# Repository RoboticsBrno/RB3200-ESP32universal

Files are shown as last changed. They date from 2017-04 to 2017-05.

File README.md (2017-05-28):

# RB3200 - ESP32 universal board

The ESP32 board you have always dreamed of by RobotikaBrno.cz!

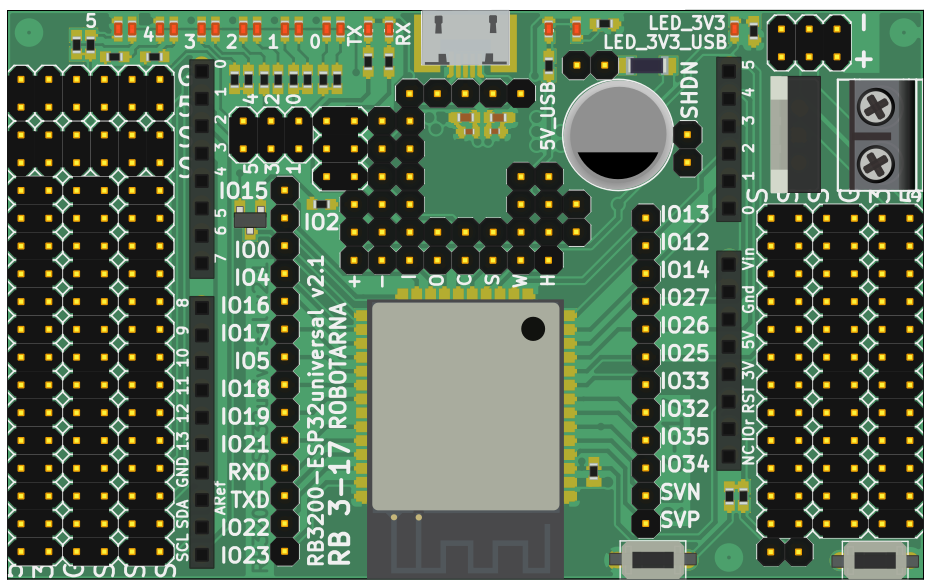
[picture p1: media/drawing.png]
Board drawing


## Features

- 4 pin headers for each of the ESP32-WROOM-32 pins
    - pin headers closest to the ESP32 module are directly exposed from the
      module
    - pin headers further from the module are protected by a serial 180R
      resistor - so you can attach e.g. a LED directly or you don't have to
      worry if you accidentally switch you grounded input to output.
    - each pin has its own 5V, 3V3 and GND pin
- Arduino Uno compatible headerincluded
- USB2Serial chip for easy button-less programming
- support for an external power supply with high-current voltage regulator
- diagnostic LEDs

## Populated board

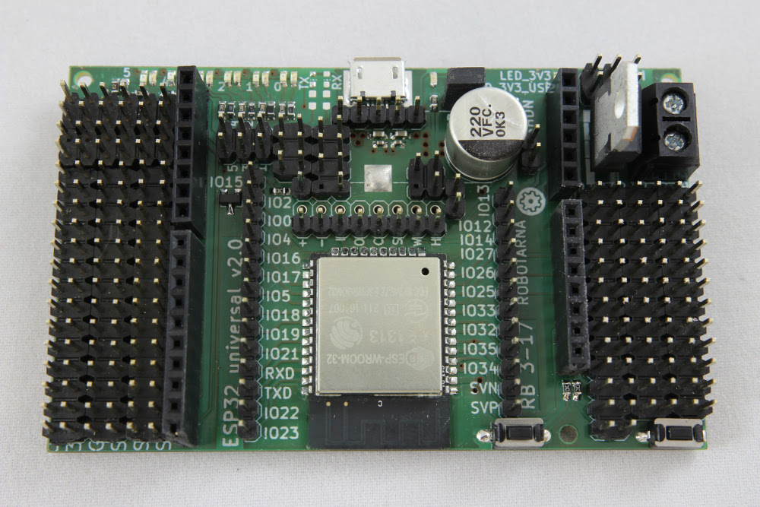
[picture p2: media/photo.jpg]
Board pohoto


## Manufacturing

There are pre-exported gerber files in the `gerbers` directory. This directory
is always up-to-date for every release (the master branch). There is also the
`bom.tsv` file which contains BOM with order codes for Farnell, TS, Mouser and
DigiKey. Note that the current development branch (`vX.Y`) does not guarantee
up-to-date gerber and BOM files.

As our board features many pin headers and you might not want to populate them
all, we did **not** include them in the BOM. Keep that please in mind when
ordering the components.

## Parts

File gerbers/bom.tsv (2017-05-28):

Qty | Value | Device | Package | Parts | Description | DIGIKEY | FARNELL | MANUFACTURER | MOUSER | MPN | RS
1 |  | PINHD-1X12 | 1X12 | JP1 | PIN HEADER
1 |  | PINHD-1X14 | 1X14 | JP5 | PIN HEADER
4 |  | PINHD-1X2 | 1X02 | EN, JP36, JP38, VUSB | PIN HEADER
1 |  | PINHD-1X5 | 1X05 | USB | PIN HEADER
1 |  | PINHD-1X8 | 1X08 | JP11 | PIN HEADER
3 |  | PINHD-2X12 | 2X12 | JP2, JP3, PWR_1 | PIN HEADER
3 |  | PINHD-2X14 | 2X14 | JP6, JP7, PWR_2 | PIN HEADER
3 |  | PINHD-2X3 | 2X03 | LEDS, VCC, VCCIO | PIN HEADER
2 |  | PINHD-2X6 | 2X06 | +5V, SERVOS | PIN HEADER
1 | 100k | R-EU_R0603 | R0603 | R37 | RESISTOR, European symbol | 311-100KHRCT-ND | 9238727 |  | 603-RC0603FR-07100KL |  | 566-787
6 | 100n/16V | C-EUC0402 | C0402 | C1, C6, C7, C11, C20, C21 | CAPACITOR, European symbol | 732-7478-1-ND | 2533923 |  | 710-885012105001 |  | 788-2871
6 | 10k | R-EU_R0603 | R0603 | R4, R5, R35, R50, R51, R52 | RESISTOR, European symbol | 311-10KGRCT-ND | 9238603 |  | 603-RC0603FR-0710KL |  | 213-2418
28 | 180R | R-EU_R0603 | R0603 | R6, R7, R8, R9, R10, R11, R12, R13, R14, R15, R16, R17, R18, R19, R20, R21, R22, R23, R24, R25, R27, R28, R29, R30, R31, R32, R33, R34 | RESISTOR, European symbol | 311-180HRCT-ND | 9238395 |  | 603-RC0603FR-07180RL |  | 566-412
1 | 1n/50V | C-EUC0603 | C0603 | C12 | CAPACITOR, European symbol | 399-1082-1-ND | 1414608 |  | 80-C0603C102K5R |  | 264-4551
1 | 330u/16V | CPOL-EUE5-10.5 | E5-10,5 | C37 | POLARIZED CAPACITOR, European symbol | 493-6629-1-ND | 9692045 |  | 140-REA331M1CBK0811P |  | 707-5840
11 | 470R | R-EU_R0603 | R0603 | R1, R2, R3, R26, R36, R38, R40, R42, R44, R46, R48 | RESISTOR, European symbol | 311-470HRCT-ND | 9238441 |  | 603-RC0603FR-07470RL |  | 566-547
4 | 4u7/16V | C-EUC0603 | C0603 | C2, C3, C4, C5 | CAPACITOR, European symbol | 478-1253-1-ND | 9227784 |  | 06034D475KAT2A |  | 698-3248
5 | 4u7/16V | C-EUC0805 | C0805 | C8, C9, C10, C67, C70 | CAPACITOR, European symbol | 1276-2970-1-ND | 2320854 |  | 963-EMK212B7475KG-T |  | 766-1037
6 | 680R | R-EU_R0603 | R0603 | R39, R41, R43, R45, R47, R49 | RESISTOR, European symbol | 311-680HRCT-ND | 9238468 |  | 603-RC0603FR-13680RL
1 | 7805 | 78XXS | 78XXS | IC2 | VOLTAGE REGULATOR | 1016-1538-5-ND | 9756078 |  | 701-SP7805V-L |  | 769-5466
1 | ARDUINOR3-BPLACE | ARDUINOR3-BPLACE | ARDUINOR3-BPLACE | U3 | This is a new object for the new Arduino R3 - with extra pins that you may want to use (such as IOref, and duplicated A4/A5
2 | BC337 | NPN-SOT23-BEC | SOT23 | T1, T2 |  | 1727-2919-1-ND | 1081224 |  | 771-BC817-40-T/R |  | 216-9410
1 | CP2102N-28 | CP2102N-28 | QFN28-PAD | IC3 |  | 336-3694-ND | 2577279 | Silicon Labs | 634-CP2102NA01GQFN28 | CP2102 | 526-8841
1 | ESP-WROOM-32 | ESP-WROOM-32 | ESP-WROOM-32 | U1 | Espressif Systems ESP-WROOM-32 | 1738-1294-ND |  | Espressif Systems |  | ESP32-WROMM-32
1 | MKDSN1,5/2-5,08 | MKDSN1,5/2-5,08 | MKDSN1,5/2-5,08 | PWR | MKDSN 1,5/ 2-5,08 Printklemme | 277-5953-ND | 2490945 |  | 651-1890963 |  | 804-5118
21 | PINH1X01 | PINH1X01 | 1X01 | !CTS, !DCD, !DSR, !DTR, !RESET, !RTS, !SUSPEND, CHR0, CHR1, CHREN, IO0/TXLED, IO1/RXLED, IO2/RS485, IO3/WAKEUP, IO4, IO5, IO6, RI/CLK, RXD, SUSPEND, TXD
2 | TACTM-35N-F | TACTM-35N-F | TACTM-35N-F | B1, B2 |  | CKN1574TR-ND | 2079520 |  | 611-PTS635SL43SMTRLF |  | 135-9609
1 | UM18533 | UM185XX | SOT23-5 | U2 |  | 296-17580-1-ND | 1135395 | Texas Instruments | 595-TPS73033DBVR | TPS73033DBVT | 620-1401
1 | USB-MICRO-B-BOTTOM | USB-MICRO-B-BOTTOM | USB-MICRO-B-BOTTOM-MOLEX | X1 |  | WM17141CT-ND | 1568026 |  | 538-47346-0001 |  | 702-5475
8 | green | LEDCHIPLED_0603 | CHIPLED_0603 | LED0P, LED1P, LED2P, LED3P, LED4P, LED5P, LED_3V3, LED_3V3_USB | LED | 160-1446-1-ND | 2293494 |  | 859-LTST-C191KGKT |  | 872-1799
6 | red | LEDCHIPLED_0603 | CHIPLED_0603 | LED0N, LED1N, LED2N, LED3N, LED4N, LED5N | LED | 160-1447-1-ND | 2322071 |  | 859-LTST-C191KRKT |  | 127-8415
3 | skl34 | SHOTTKY-SOD123 | SOD123 | D1, D2, D5
3 | yellow | LEDCHIP-LED0603 | CHIP-LED0603 | LED1, LED2, LED3 | LED | 732-4981-1-ND | 2322074 |  | 710-150060YS75000 |  | 815-4219

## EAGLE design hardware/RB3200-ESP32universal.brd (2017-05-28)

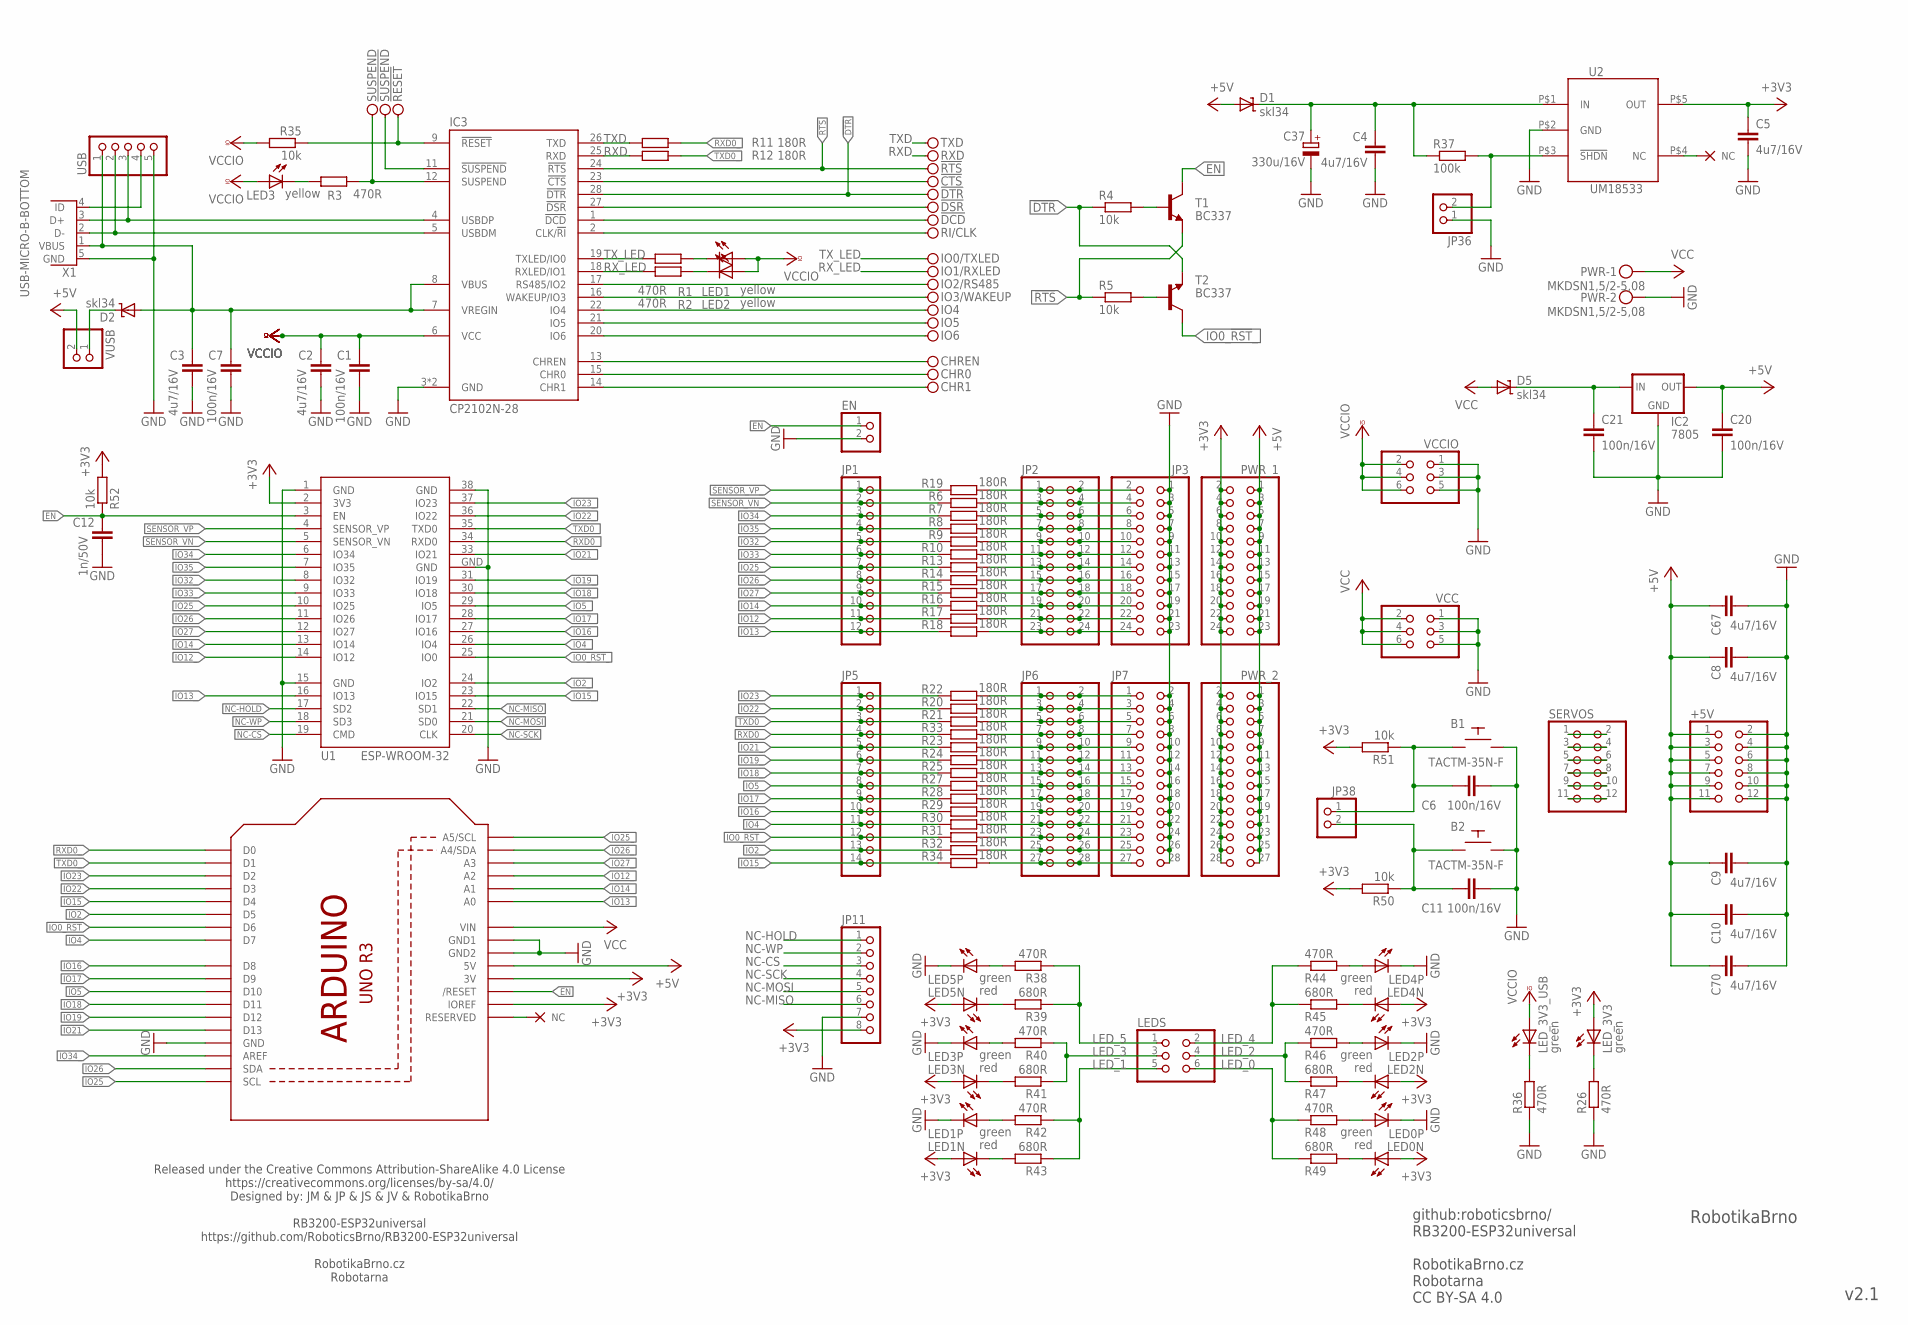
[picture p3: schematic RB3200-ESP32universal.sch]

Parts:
!CTS: PINH1X01; 1X01; DIGIKEY WM14724-ND
!DCD: PINH1X01; 1X01; DIGIKEY WM14724-ND
!DSR: PINH1X01; 1X01; DIGIKEY WM14724-ND
!DTR: PINH1X01; 1X01; DIGIKEY WM14724-ND
!RESET: PINH1X01; 1X01; DIGIKEY WM14724-ND
!RTS: PINH1X01; 1X01; DIGIKEY WM14724-ND
!SUSPEND: PINH1X01; 1X01; DIGIKEY WM14724-ND
+5V: PINHD-2X6; 2X06; DIGIKEY A122662-ND
B1, B2: TACTM-35N-F; DIGIKEY CKN1574TR-ND
C1, C6, C7, C11, C20, C21: 100n/16V; C0402; DIGIKEY 732-7478-1-ND
C2, C3, C4, C5: 4u7/16V; C0603; DIGIKEY 478-1253-1-ND
C8, C9, C10, C67, C70: 4u7/16V; C0805; DIGIKEY 1276-2970-1-ND
C12: 1n/50V; C0603; DIGIKEY 399-1082-1-ND
C37: 330u/16V; E5-10,5; DIGIKEY 493-6629-1-ND
CHR0, CHR1: PINH1X01; 1X01; DIGIKEY WM14724-ND
CHREN: PINH1X01; 1X01; DIGIKEY WM14724-ND
D1, D2, D5: skl34; SOD123
EN: PINHD-1X2; 1X02; DIGIKEY 3M9457-02-ND
IC2: 7805; 78XXS; DIGIKEY 1016-1538-5-ND
IC3: CP2102N-28; QFN28-PAD; MPN CP2102; DIGIKEY 336-3694-ND
IO0/TXLED, IO1/RXLED, IO2/RS485, IO3/WAKEUP, IO4, IO5, IO6: PINH1X01; 1X01; DIGIKEY WM14724-ND
JP1: PINHD-1X12; 1X12; DIGIKEY WM50014-12-ND
JP2, JP3: PINHD-2X12; 2X12; DIGIKEY WM8148-ND
JP5: PINHD-1X14; 1X14; FARNELL 2356164
JP6, JP7: PINHD-2X14; 2X14; DIGIKEY WM8150-ND
JP11: PINHD-1X8; 1X08; DIGIKEY A122911-ND
JP36, JP38: PINHD-1X2; 1X02; DIGIKEY 3M9457-02-ND
LED0N, LED1N, LED2N, LED3N, LED4N, LED5N: red; CHIPLED_0603; DIGIKEY 160-1447-1-ND
LED0P, LED1P, LED2P, LED3P, LED4P, LED5P: green; CHIPLED_0603; DIGIKEY 160-1446-1-ND
LED1, LED2, LED3: yellow; CHIP-LED0603; DIGIKEY 732-4981-1-ND
LEDS: PINHD-2X3; 2X03; DIGIKEY A122915-ND
LED_3V3, LED_3V3_USB: green; CHIPLED_0603; DIGIKEY 160-1446-1-ND
PWR: MKDSN1,5/2-5,08; DIGIKEY 277-5953-ND
PWR_1: PINHD-2X12; 2X12; DIGIKEY WM8148-ND
PWR_2: PINHD-2X14; 2X14; DIGIKEY WM8150-ND
R1, R2, R3, R26, R36, R38, R40, R42, R44, R46, R48: 470R; R0603; DIGIKEY 311-470HRCT-ND
R4, R5, R35, R50, R51, R52: 10k; R0603; DIGIKEY 311-10KGRCT-ND
R6, R7, R8, R9, R10, R11, R12, R13, R14, R15, R16, R17, R18, R19, R20, R21, R22, R23, R24, R25, R27, R28, R29, R30, R31, R32, R33, R34: 180R; R0603; DIGIKEY 311-180HRCT-ND
R37: 100k; R0603; DIGIKEY 311-100KHRCT-ND
R39, R41, R43, R45, R47, R49: 680R; R0603; DIGIKEY 311-680HRCT-ND
RI/CLK: PINH1X01; 1X01; DIGIKEY WM14724-ND
RXD: PINH1X01; 1X01; DIGIKEY WM14724-ND
SERVOS: PINHD-2X6; 2X06; DIGIKEY A122662-ND
SUSPEND: PINH1X01; 1X01; DIGIKEY WM14724-ND
T1, T2: BC337; SOT23; DIGIKEY 1727-2919-1-ND
TXD: PINH1X01; 1X01; DIGIKEY WM14724-ND
U1: ESP-WROOM-32; MPN ESP32-WROMM-32; DIGIKEY 1738-1294-ND
U2: UM18533; SOT23-5; MPN TPS73033DBVT; DIGIKEY 296-17580-1-ND
U3: ARDUINOR3-BPLACE
USB: PINHD-1X5; 1X05; DIGIKEY 732-5318-ND
VCC: PINHD-2X3; 2X03; DIGIKEY A122915-ND
VCCIO: PINHD-2X3; 2X03; DIGIKEY A122915-ND
VUSB: PINHD-1X2; 1X02; DIGIKEY 3M9457-02-ND
X1: USB-MICRO-B-BOTTOM; USB-MICRO-B-BOTTOM-MOLEX; DIGIKEY WM17141CT-ND

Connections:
3V3_IN: C4.1, C37.+, D1.C, R37.1, U2.P$1 (IN)
5V_USB: D2.C, VUSB.1
!DTR: !DTR.1, IC3.28 (!DTR), R4.1, T2.2 (E)
!DTR_B: R4.2, T1.1 (B)
!RESET: !RESET.1, IC3.9 (!RESET), R35.1
!RTS: !RTS.1, IC3.24 (!RTS), R5.1, T1.2 (E)
!RTS_B: R5.2, T2.1 (B)
!SHDN: JP36.2, R37.2, U2.P$3 (!SHDN)
!SUSPEND: !SUSPEND.1, IC3.11 (!SUSPEND)
+3V3: C5.1, JP11.8, LED0N.A, LED1N.A, LED2N.A, LED3N.A, LED4N.A, LED5N.A, LED_3V3.A, PWR_1.2, PWR_1.4, PWR_1.6, PWR_1.8, PWR_1.10, PWR_1.12, PWR_1.14, PWR_1.16, PWR_1.18, PWR_1.20, PWR_1.22, PWR_1.24, PWR_2.2, PWR_2.4, PWR_2.6, PWR_2.8, PWR_2.10, PWR_2.12, PWR_2.14, PWR_2.16, PWR_2.18, PWR_2.20, PWR_2.22, PWR_2.24, PWR_2.26, PWR_2.28, R50.2, R51.2, R52.2, U1.2 (3V3), U2.P$5 (OUT), U3.3V, U3.IOREF
+5V: +5V.1, +5V.3, +5V.5, +5V.7, +5V.9, +5V.11, C8.1, C9.1, C10.1, C20.1, C67.1, C70.1, D1.A, IC2.OUT, PWR_1.1, PWR_1.3, PWR_1.5, PWR_1.7, PWR_1.9, PWR_1.11, PWR_1.13, PWR_1.15, PWR_1.17, PWR_1.19, PWR_1.21, PWR_1.23, PWR_2.1, PWR_2.3, PWR_2.5, PWR_2.7, PWR_2.9, PWR_2.11, PWR_2.13, PWR_2.15, PWR_2.17, PWR_2.19, PWR_2.21, PWR_2.23, PWR_2.25, PWR_2.27, U3.5V, VUSB.2
BTN0: B1.P$4, C6.2, JP38.1, R51.1
BTN1: B2.P$4, C11.2, JP38.2, R50.1
CHR0: CHR0.1, IC3.15 (CHR0)
CHR1: CHR1.1, IC3.14 (CHR1)
CHREN: CHREN.1, IC3.13 (CHREN)
CLK/!RI: IC3.2 (CLK/!RI), RI/CLK.1
DCD: !DCD.1, IC3.1 (!DCD)
DM: IC3.5 (USBDM), USB.2, X1.2 (D-)
DP: IC3.4 (USBDP), USB.3, X1.3 (D+)
DSR: !DSR.1, IC3.27 (!DSR)
EN: C12.1, EN.1, R52.1, T1.3 (C), U1.3 (EN), U3.RESET (/RESET)
GND: +5V.2, +5V.4, +5V.6, +5V.8, +5V.10, +5V.12, B1.P$2, B2.P$2, C1.2, C2.2, C3.2, C4.2, C5.2, C6.1, C7.2, C8.2, C9.2, C10.2, C11.1, C12.2, C20.2, C21.2, C37.-, C67.2, C70.2, EN.2, IC2.GND, IC3.3 (GND), IC3.PAD (GND), JP3.1, JP3.3, JP3.5, JP3.7, JP3.9, JP3.11, JP3.13, JP3.15, JP3.17, JP3.19, JP3.21, JP3.23, JP7.2, JP7.4, JP7.6, JP7.8, JP7.10, JP7.12, JP7.14, JP7.16, JP7.18, JP7.20, JP7.22, JP7.24, JP7.26, JP7.28, JP11.7, JP36.1, LED0P.C, LED1P.C, LED2P.C, LED3P.C, LED4P.C, LED5P.C, PWR.2, R26.1, R36.1, U1.1 (GND), U1.15 (GND), U1.38 (GND), U1.GND, U2.P$2 (GND), U3.GND, U3.GND1, U3.GND2, USB.5, VCC.1, VCC.3, VCC.5, VCCIO.1, VCCIO.3, VCCIO.5, X1.5 (GND)
IO0_!RST: JP6.23, JP6.24, JP7.23, R31.1, U3.D6
IO0_!RST!_: JP5.12, R31.2, T2.3 (C), U1.25 (IO0)
IO2: JP6.25, JP6.26, JP7.25, R32.1, U3.D5
IO2_: JP5.13, R32.2, U1.24 (IO2)
IO4: JP6.21, JP6.22, JP7.21, R30.1, U3.D7
IO4_: JP5.11, R30.2, U1.26 (IO4)
IO5: JP6.15, JP6.16, JP7.15, R27.1, U3.D10
IO5_: JP5.8, R27.2, U1.29 (IO5)
IO12: JP2.21, JP2.22, JP3.22, R17.1
IO12_: JP1.11, R17.2, U1.14 (IO12), U3.A2
IO13: JP2.23, JP2.24, JP3.24, R18.1
IO13_: JP1.12, R18.2, U1.16 (IO13), U3.A0
IO14: JP2.19, JP2.20, JP3.20, R16.1
IO14_: JP1.10, R16.2, U1.13 (IO14), U3.A1
IO15: JP6.27, JP6.28, JP7.27, R34.1, U3.D4
IO15_: JP5.14, R34.2, U1.23 (IO15)
IO16: JP6.19, JP6.20, JP7.19, R29.1, U3.D8
IO16_: JP5.10, R29.2, U1.27 (IO16)
IO17: JP6.17, JP6.18, JP7.17, R28.1, U3.D9
IO17_: JP5.9, R28.2, U1.28 (IO17)
IO18: JP6.13, JP6.14, JP7.13, R25.1, U3.D11
IO18_: JP5.7, R25.2, U1.30 (IO18)
IO19: JP6.11, JP6.12, JP7.11, R24.1, U3.D12
IO19_: JP5.6, R24.2, U1.31 (IO19)
IO21: JP6.9, JP6.10, JP7.9, R23.1, U3.D13
IO21_: JP5.5, R23.2, U1.33 (IO21)
IO22: JP6.3, JP6.4, JP7.3, R20.1, U3.D3
IO22_: JP5.2, R20.2, U1.36 (IO22)
IO23: JP6.1, JP6.2, JP7.1, R22.1, U3.D2
IO23_: JP5.1, R22.2, U1.37 (IO23)
IO25: JP2.13, JP2.14, JP3.14, R13.1
IO25_: JP1.7, R13.2, U1.10 (IO25), U3.A5 (A5/SCL), U3.SCL
IO26: JP2.15, JP2.16, JP3.16, R14.1
IO26_: JP1.8, R14.2, U1.11 (IO26), U3.A4 (A4/SDA), U3.SDA
IO27: JP2.17, JP2.18, JP3.18, R15.1
IO27_: JP1.9, R15.2, U1.12 (IO27), U3.A3
IO32: JP2.9, JP2.10, JP3.10, R9.1
IO32_: JP1.5, R9.2, U1.8 (IO32)
IO33: JP2.11, JP2.12, JP3.12, R10.1
IO33_: JP1.6, R10.2, U1.9 (IO33)
IO34: JP2.5, JP2.6, JP3.6, R7.1
IO34_: JP1.3, R7.2, U1.6 (IO34), U3.AREF
IO35: JP2.7, JP2.8, JP3.8, R8.1
IO35_: JP1.4, R8.2, U1.7 (IO35)
LED0N: LED0N.C, R49.2
LED0P: LED0P.A, R48.2
LED1N: LED1N.C, R43.2
LED1P: LED1P.A, R42.2
LED2N: LED2N.C, R47.2
LED2P: LED2P.A, R46.2
LED3N: LED3N.C, R41.2
LED3P: LED3P.A, R40.2
LED4N: LED4N.C, R45.2
LED4P: LED4P.A, R44.2
LED5N: LED5N.C, R39.2
LED5P: LED5P.A, R38.2
LED_0: LEDS.6, R48.1, R49.1
LED_1: LEDS.5, R42.1, R43.1
LED_2: LEDS.4, R46.1, R47.1
LED_3: LEDS.3, R40.1, R41.1
LED_3V3: LED_3V3.C, R26.2
LED_3V3_USB: LED_3V3_USB.C, R36.2
LED_4: LEDS.2, R44.1, R45.1
LED_5: LEDS.1, R38.1, R39.1
unnamed: !CTS.1, IC3.23 (!CTS)
unnamed: LED3.C, R3.2
unnamed: SERVOS.1, SERVOS.2
unnamed: SERVOS.3, SERVOS.4
unnamed: SERVOS.5, SERVOS.6
unnamed: SERVOS.7, SERVOS.8
unnamed: SERVOS.9, SERVOS.10
unnamed: SERVOS.11, SERVOS.12
NC-CS: JP11.3, U1.19 (CMD)
NC-HOLD: JP11.1, U1.17 (SD2)
NC-MISO: JP11.6, U1.22 (SD1)
NC-MOSI: JP11.5, U1.21 (SD0)
NC-SCK: JP11.4, U1.20 (CLK)
NC-WP: JP11.2, U1.18 (SD3)
RX-LED: LED2.C, R2.1
RXD: IC3.25 (RXD), R12.1, RXD.1
RXD0: JP6.7, JP6.8, JP7.7, R33.1, U3.D0
RXD0_: JP5.4, R11.2, R33.2, U1.34 (RXD0)
RX_LED: IC3.18 (RXLED/IO1), IO1/RXLED.1, R2.2
SENSOR_VN: JP2.3, JP2.4, JP3.4, R6.1
SENSOR_VN_: JP1.2, R6.2, U1.5 (SENSOR_VN)
SENSOR_VP: JP2.1, JP2.2, JP3.2, R19.1
SENSOR_VP_: JP1.1, R19.2, U1.4 (SENSOR_VP)
SUSPEND: IC3.12 (SUSPEND), R3.1, SUSPEND.1
TX-LED: LED1.C, R1.1
TXD: IC3.26 (TXD), R11.1, TXD.1
TXD0: JP6.5, JP6.6, JP7.5, R21.1, U3.D1
TXD0_: JP5.3, R12.2, R21.2, U1.35 (TXD0)
TX_LED: IC3.19 (TXLED/IO0), IO0/TXLED.1, R1.2
U2_NC: U2.P$4 (NC)
USBID: USB.4, X1.4 (ID)
USBIO3_RS485: IC3.17 (RS485/IO2), IO2/RS485.1
USBIO3_WAKEUP: IC3.16 (WAKEUP/IO3), IO3/WAKEUP.1
USBIO4: IC3.22 (IO4), IO4.1
USBIO5: IC3.21 (IO5), IO5.1
USBIO6: IC3.20 (IO6), IO6.1
VCC: D5.A, PWR.1, VCC.2, VCC.4, VCC.6
VCC->5V: C21.1, D5.C, IC2.IN
VCCIO: C1.1, C2.1, IC3.6 (VCC), LED1.A, LED2.A, LED3.A, LED_3V3_USB.A, R35.2, VCCIO.2, VCCIO.4, VCCIO.6
VUSB: C3.1, C7.1, D2.A, IC3.7 (VREGIN), IC3.8 (VBUS), USB.1, X1.1 (VBUS)

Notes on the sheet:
github:roboticsbrno/ RB3200-ESP32universal RobotikaBrno.cz Robotarna CC BY-SA 4.0
RobotikaBrno
v2.1
Released under the Creative Commons Attribution-ShareAlike 4.0 License https://creativecommons.org/licenses/by-sa/4.0/ Designed by: JM & JP & JS & JV & RobotikaBrno RB3200-ESP32universal https://github.com/RoboticsBrno/RB3200-ESP32universal RobotikaBrno.cz Robotarna

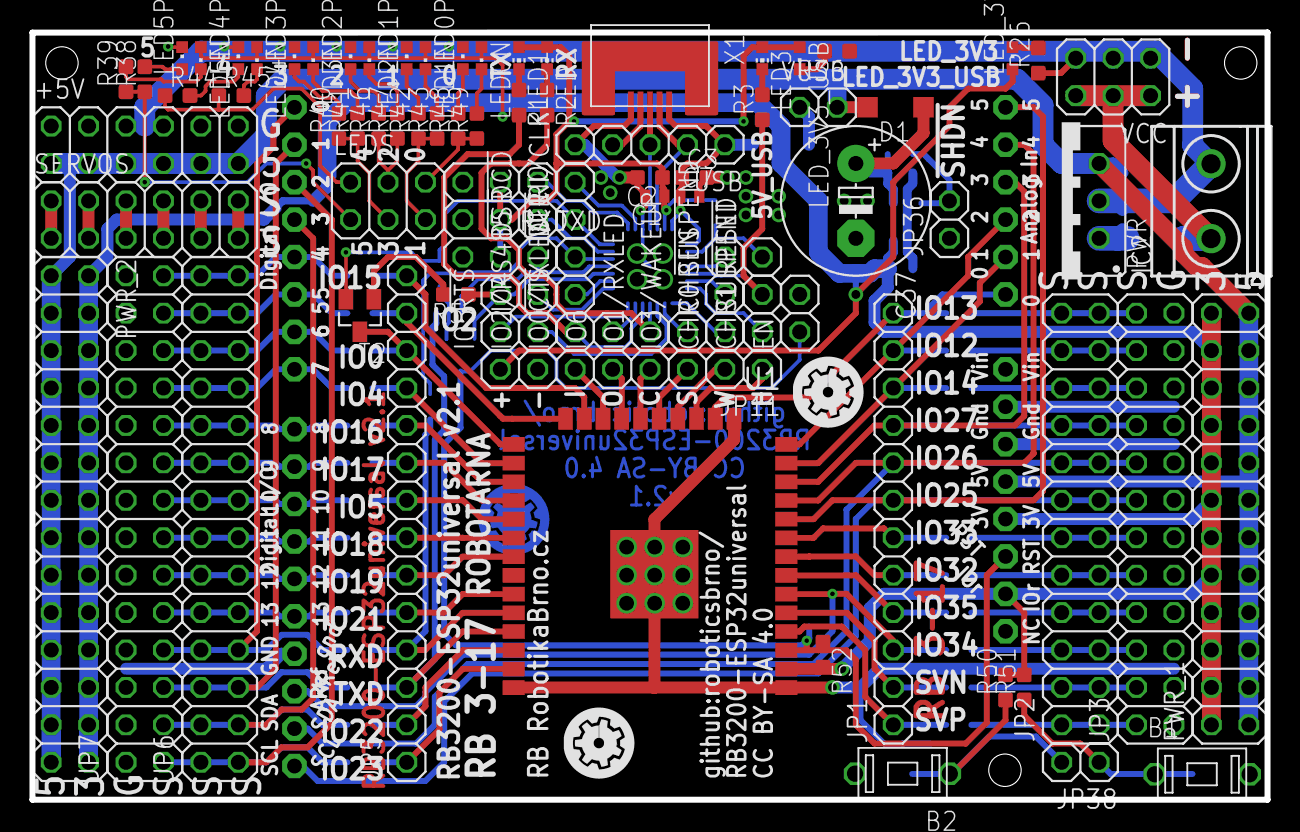
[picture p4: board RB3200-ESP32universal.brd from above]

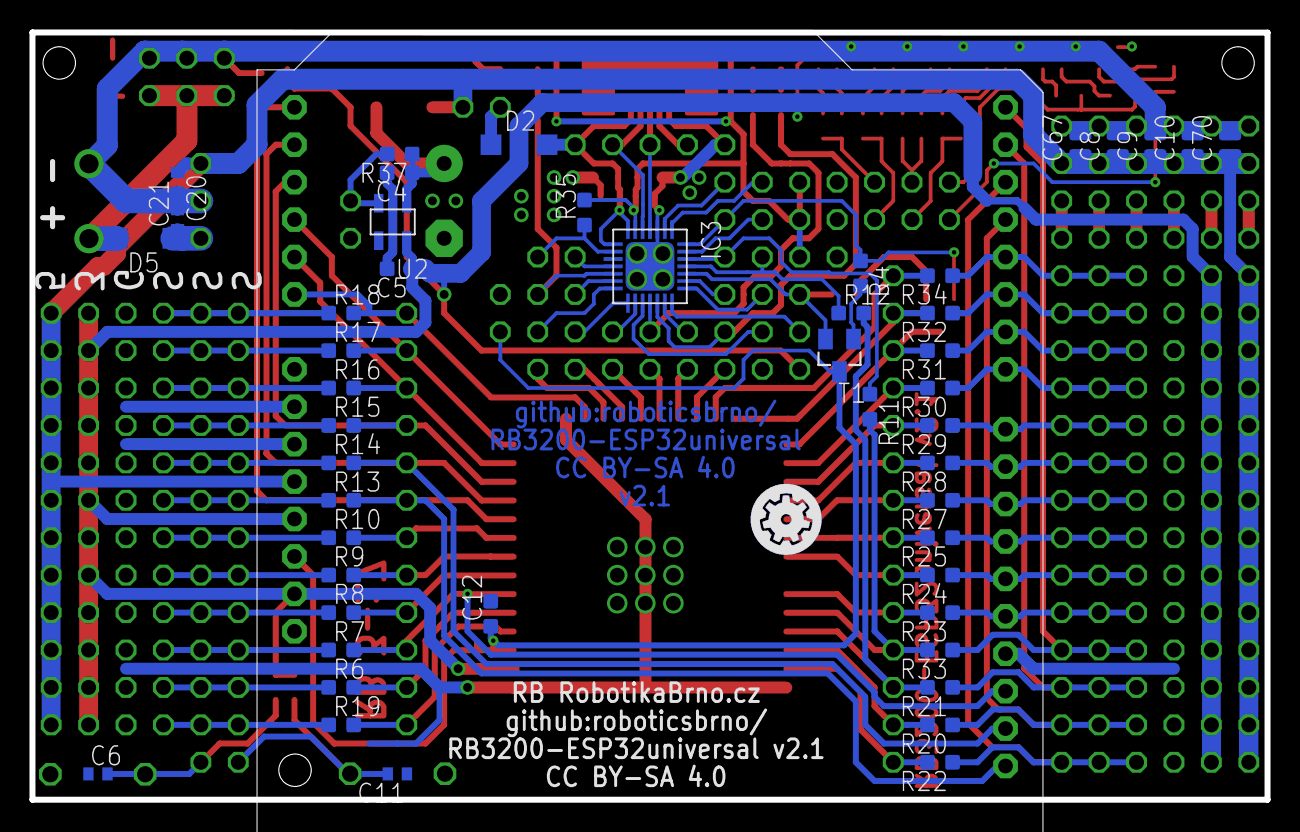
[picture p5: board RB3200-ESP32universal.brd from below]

Board: 2 copper layers, 83.8 x 52.1 mm, 140 parts (48 on the bottom side), 126 nets.

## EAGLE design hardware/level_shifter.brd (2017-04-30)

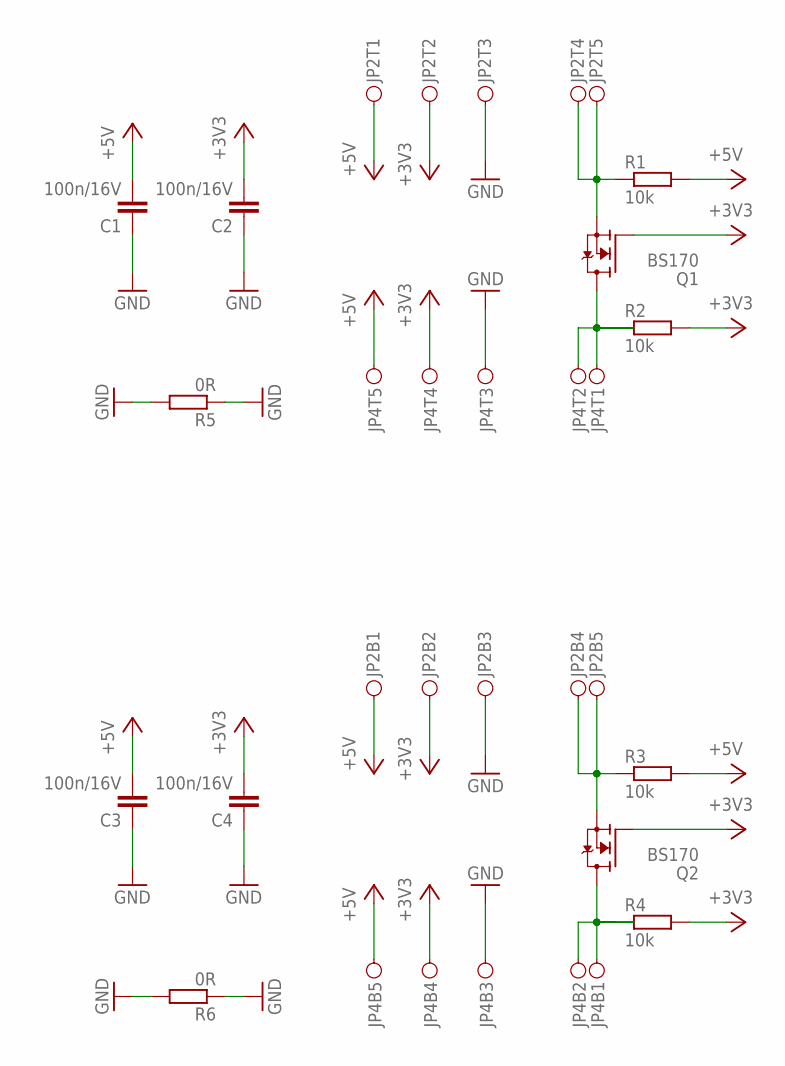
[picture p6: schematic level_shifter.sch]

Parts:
C1, C2, C3, C4: 100n/16V; C0603S
JP2, JP4: PINH2X05; PINH2X05SMD
Q1: BS170; SOT23_DIST
Q2: BS170; SOT23
R1, R2, R3, R4: 10k; R0603S
R5, R6: 0R; R1206S

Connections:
+3V3: C2.2, C4.2, JP2.B2, JP2.T2, JP4.B4, JP4.T4, Q1.1 (G), Q2.1 (G), R2.2, R4.2
+5V: C1.2, C3.2, JP2.B1, JP2.T1, JP4.B5, JP4.T5, R1.2, R3.2
GND: C1.1, C2.1, C3.1, C4.1, JP2.B3, JP2.T3, JP4.B3, JP4.T3, R5.1, R5.2, R6.1, R6.2
IN_B: JP4.B1, JP4.B2, Q2.3 (D), R4.1
IN_T: JP4.T1, JP4.T2, Q1.3 (D), R2.1
OUT_B: JP2.B4, JP2.B5, Q2.2 (S), R3.1
OUT_T: JP2.T4, JP2.T5, Q1.2 (S), R1.1

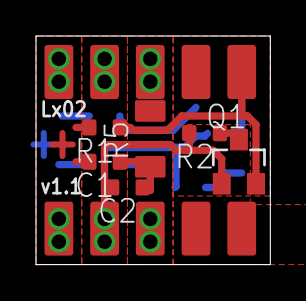
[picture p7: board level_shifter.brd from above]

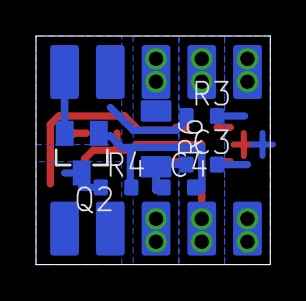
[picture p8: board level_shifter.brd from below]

Board: 2 copper layers, 13.0 x 12.7 mm, 14 parts (6 on the bottom side), 7 nets.

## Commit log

2017-04-07 Publish version 1.0
    [RB3200-ESP32universal.brd, RB3200-ESP32universal.sch]
2017-04-07 Add information text about license and authors
    [RB3200-ESP32universal.brd, RB3200-ESP32universal.sch]
2017-04-30 Publish version 2.0 of RB3200-ESP32universal and level_shifter DPS
    [RB3200-ESP32universal.brd, RB3200-ESP32universal.sch, level_shifter.brd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]
2017-04-30 updated silkscreen (and added bSilk)
    [RB3200-ESP32universal.brd, RB3200-ESP32universal.sch]
2017-04-30 shrunk level_shifter by one signal pinhead
    [level_shifter.brd, level_shifter.sch]
2017-05-01 outline of C37 in horizontal position moved to layer reference
    [RB3200-ESP32universal.brd]
2017-05-02 Make pin header pads octagonal
    [RB3200-ESP32universal.brd, RB3200-ESP32universal.sch]
2017-05-02 Move labels to layer 21
    Allows for easy KiCAD import.
    [RB3200-ESP32universal.brd]
2017-05-25 Add enable pullup
    This solves board flashing issues.
    [RB3200-ESP32universal.brd, RB3200-ESP32universal.sch]
2017-05-25 Change EN pullup value to simplify BOM
    [RB3200-ESP32universal.brd, RB3200-ESP32universal.sch]
2017-05-25 Add gerbers for Kitnic
    [RB3200-ESP32universal.GBL, RB3200-ESP32universal.GBO, RB3200-ESP32universal.GBP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]
2017-05-27 Add order codes to the components.
    [RB3200-ESP32universal.brd, RB3200-ESP32universal.sch, bom.tsv]
2017-05-27 Add MPM to the BOM
    [bom.tsv]
2017-05-27 Add unit info into the gerber drill file
2017-05-28 Tweak BOM according to #4
    [RB3200-ESP32universal.brd, RB3200-ESP32universal.sch, bom.tsv]
2017-05-28 Remove order codes for pin headers from BOM, add readme note
    [bom.tsv]

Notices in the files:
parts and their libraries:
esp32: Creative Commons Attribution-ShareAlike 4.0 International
